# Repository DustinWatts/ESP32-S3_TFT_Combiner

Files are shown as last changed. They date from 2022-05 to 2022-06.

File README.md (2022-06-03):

# ESP32-S3-DevKitC-1 + Touchscreen Combiner PCB







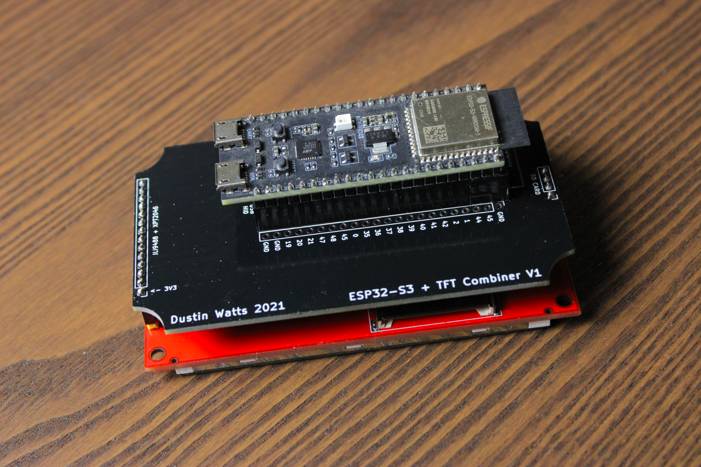
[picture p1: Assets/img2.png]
ESP32-S3-DevKitC-1 + Touchscreen Combiner PCB


A PCB making it easy to combine an ESP32-S3-DevKitC-1 and an ILI9488 TFT + XPT2046 Touchsceen. ***One big adavantage of the ESP32-S3 is that is has USB HID support. So you can use the extra USB port on the DevKitC to connect to your computer, so you can use a USB Keyboard instead of BLE!*** FreeTouchDeck already support this.

## Order directly from PCBWay

You can order the PCB's directly from PCBWay here: [Order PCBs from PCBWay](https://www.pcbway.com/project/shareproject/ESP32_S3_TFT_Combiner_V1_92bd8d61.html "Order the combiner board directly from PCBWay")

## Download Gebers and use your own fab house

If you want to use your own fab house, you can find the gerbers (as wel as a .zip file for easy upload) in the [Gerber folder](/Gerbers "Download the gerbers") in this repo.

## The PCB

The PCB is designed in KiCad and uses 22-pin double row headers for the ESP32-S3 so you can use the GPIO's not used by the screen. It also uses a 14-pin header for the screen and a 4-pin header for the SD card. I recommend using female headers so you can remove both the ESP32-S3 and the screen.

Pins used by the screen, touchcontroller and SD card are:

| ESP32-S3 | Function |
|---|---|
| GPIO4  | SD_SELECT  |
| GPIO5  | TFT_RESET  |
| GPIO6  | TFT_DC_RS  |
| GPIO7  | TFT_BACKLIGHT  |
| GPIO10  | TFT_SELECT  |
| GPIO11  | MOSI  |
| GPIO12  | SCK  |
| GPIO13  | MISO  |
| GPIO15  | TOUCH_SELECT  |
| GPIO16  | TOUCH_IRQ  |

And off course 3V3 and GND are connected to the screen. 

The rest of the pins you can freely use. Use the ESP32-S3-DevKitC-1 pinout card as a reference: [Pinout Card on espressif.com](https://docs.espressif.com/projects/esp-idf/en/latest/esp32s3/hw-reference/esp32s3/user-guide-devkitc-1.html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 "ESP32-S3-DevKitC-1 Pinout Card")

## The ESP32-S3
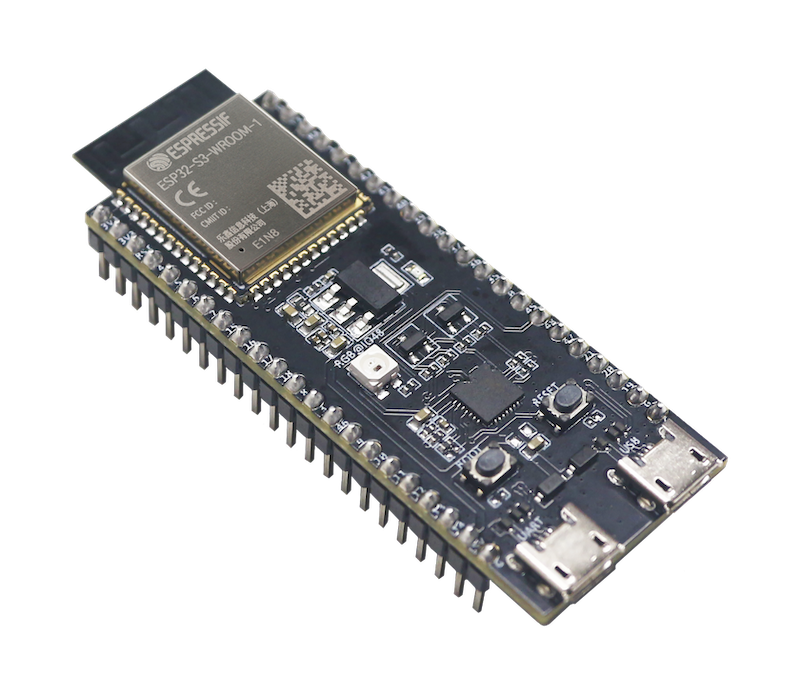
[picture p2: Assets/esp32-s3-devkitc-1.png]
ESP32-S3-DevKitC-1


The ESP32-S3 for this board is the ESP32-S3-DevKitC-1. Which is currently sold by:
- [Mouser](https://www.mouser.com/c/?q=ESP32-S3-DevKitC-1 "ESP32-S3-DevKitC-1 on Mouser")
- [DigiKey](https://www.digikey.nl/en/products/filter/rf-evaluation-and-development-kits-boards/859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 "ESP32-S3-DevKitC-1 on DigiKey")
- [Adafruit](https://www.adafruit.com/?q=ESP32-S3-DevKitC-1&sort=BestMatch "ESP32-S3-DevKitC-1 on Adafruit")
- [MakerFabs](https://www.makerfabs.com/search.html?&search=ESP32-S3-DevKitC-1 "ESP32-S3-DevKitC-1 on MakerFabs")

## The Touchsceen

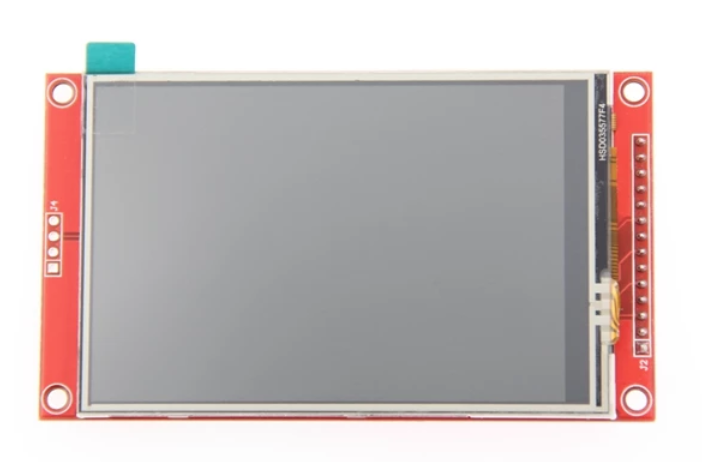
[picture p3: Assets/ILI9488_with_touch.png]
ILI9488 with Touch


The touchscreen used with this board is a 3.5" ILI9488 TFT with XPT2046 touchcontroller. You can find the screen here: 

- [AliExpress](https://s.click.aliexpress.com/e/_AMAa6B "Buy the ILI9488 with Touch on AliExpress") *
- [Amazon](https://amzn.to/3z2bf3f "Buy the ILI9488 with Touch on AliExpress") *

_* Afilliate link_

***Note: When you but the ILI9488 make sure you select the option "With Touch" if you have the possibility to do so!***

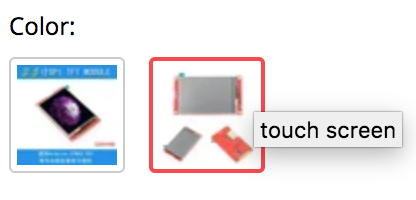
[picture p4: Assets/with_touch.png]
ILI9488 select with Touch


## The User_Setup.h

The User_Setup.h file in the folder with the same name is the User_Setup.h file you need to use the combiner PCB with the [TFT_eSPI](https://github.com/Bodmer/TFT_eSPI "TFT_eSPI lbrary by Bodmer") lbrary by Bodmer. Overwrite the contents of the original file and TFT_eSPI is now configured for use with the combiner board.

## FreeTouchDeck

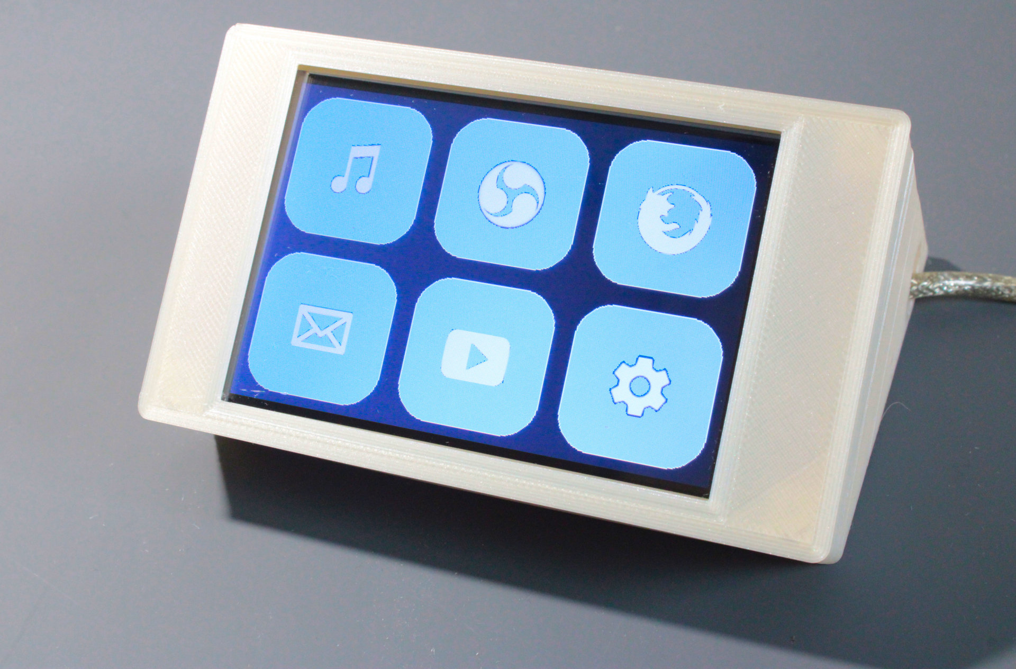
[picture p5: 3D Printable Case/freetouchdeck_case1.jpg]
FreeTouchDeck


FreeTouchDeck is currently being updated so it also supports the ESP32-S3. This also includes support for using the ESP32-S3 USB Keyboard HID. You can find the latest version here: https://github.com/DustinWatts/FreeTouchDeck. The updates are not in any release yet, you so you will have to download the source and compile it yourself. Hopefully this the next release will include ESP32-S3 support.

## The Case
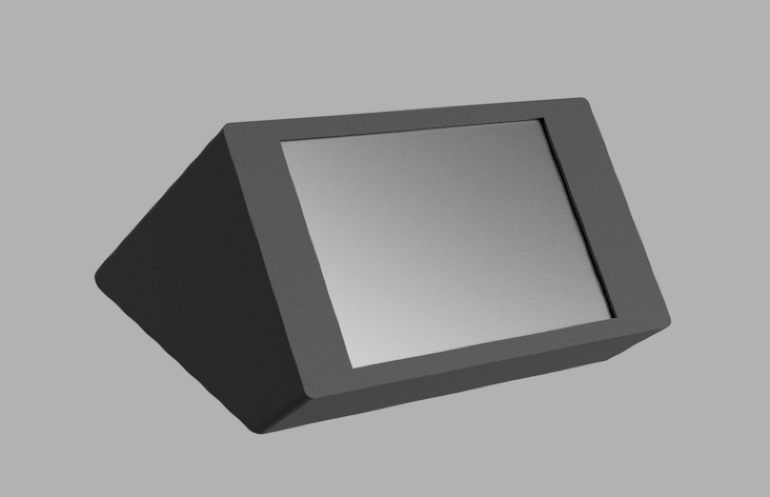
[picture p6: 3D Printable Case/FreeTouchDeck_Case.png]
3D Printable Case


The case was originally designed for the ESP32 + TFT combiner PCB and for use with FreeTouchDeck. But since the deminsions are the same, the case is also the same. You can find the .stl files to prin your own case in this repo in the folder called "3D Printable Case".

## Support Me

If you like what I am doing, there are a number of ways you can support me. 

| Platform | Link|
|:-----:|:-----|
| [Twtter](https://twitter.com/dustinwattsnl "Follow me on Twitter") | You can follow me on Twitter: [@dustinwattsnl](https://twitter.com/dustinwattsnl "Follow me on Twitter")|
| [YouTube](https://www.youtube.com/dustinwatts "Subscrive to my YouTube channel") | You can subscribe to my channel on Youtube: [/dustinWatts](https://www.youtube.com/dustinwatts "Subscribe to my YouTube channel") |
| [Patreon](https://www.patreon.com/dustinwatts) | You can support me by becoming a patron on Patreon: https://www.patreon.com/dustinwatts |
| [PayPal.me](https://www.paypal.me/dustinwattsnl) | You can make a one time donation using PayPal.me: https://www.paypal.me/dustinwattsnl |

## Get help

For quick acces to help you can join my Discord server: https://discord.gg/RE3XevS

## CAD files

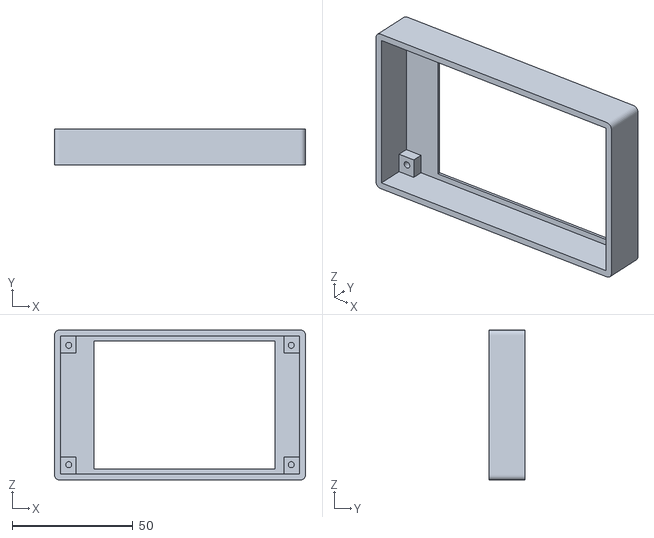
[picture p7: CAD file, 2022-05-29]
3D Printable Case/Top.stl
104.1 x 15.1 x 62.1

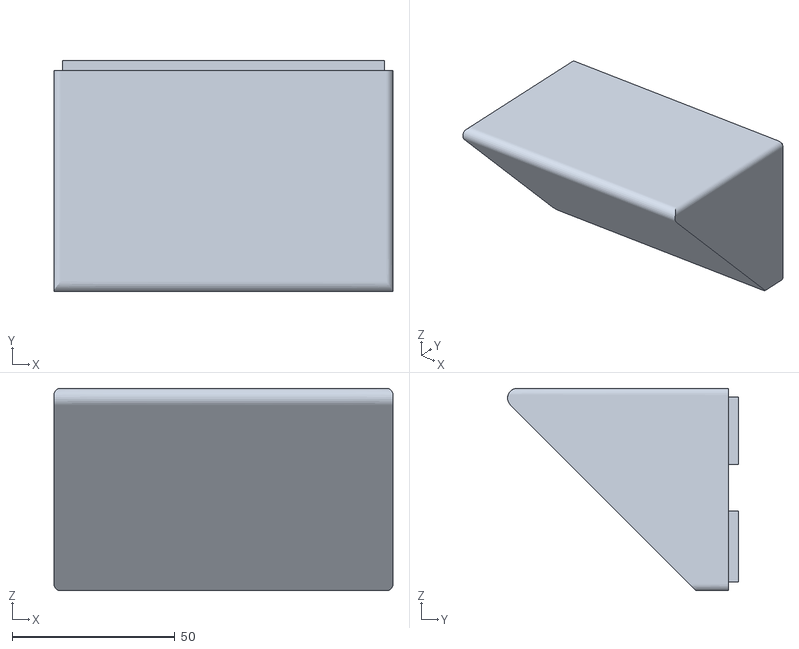
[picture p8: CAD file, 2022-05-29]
3D Printable Case/Bottom.stl
104.1 x 70.9 x 62.1

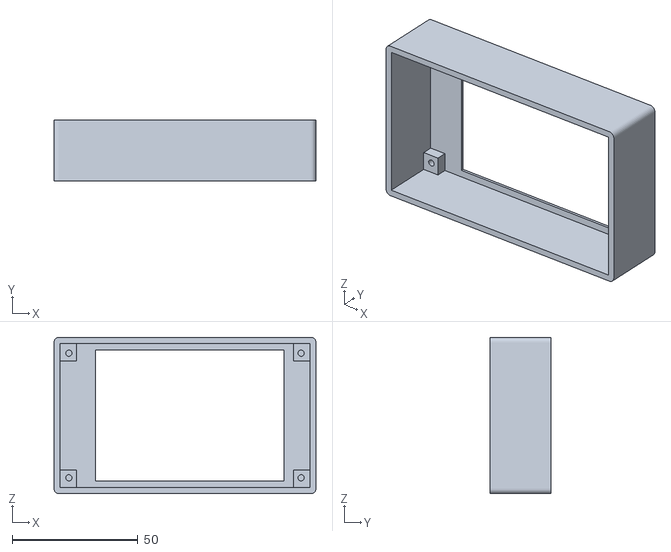
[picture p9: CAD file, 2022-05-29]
3D Printable Case/Top_for_TFT_with_Headers.stl
104.1 x 24.1 x 62.1

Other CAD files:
3D Printable Case/FreeTouchDeck Case V1.f3z

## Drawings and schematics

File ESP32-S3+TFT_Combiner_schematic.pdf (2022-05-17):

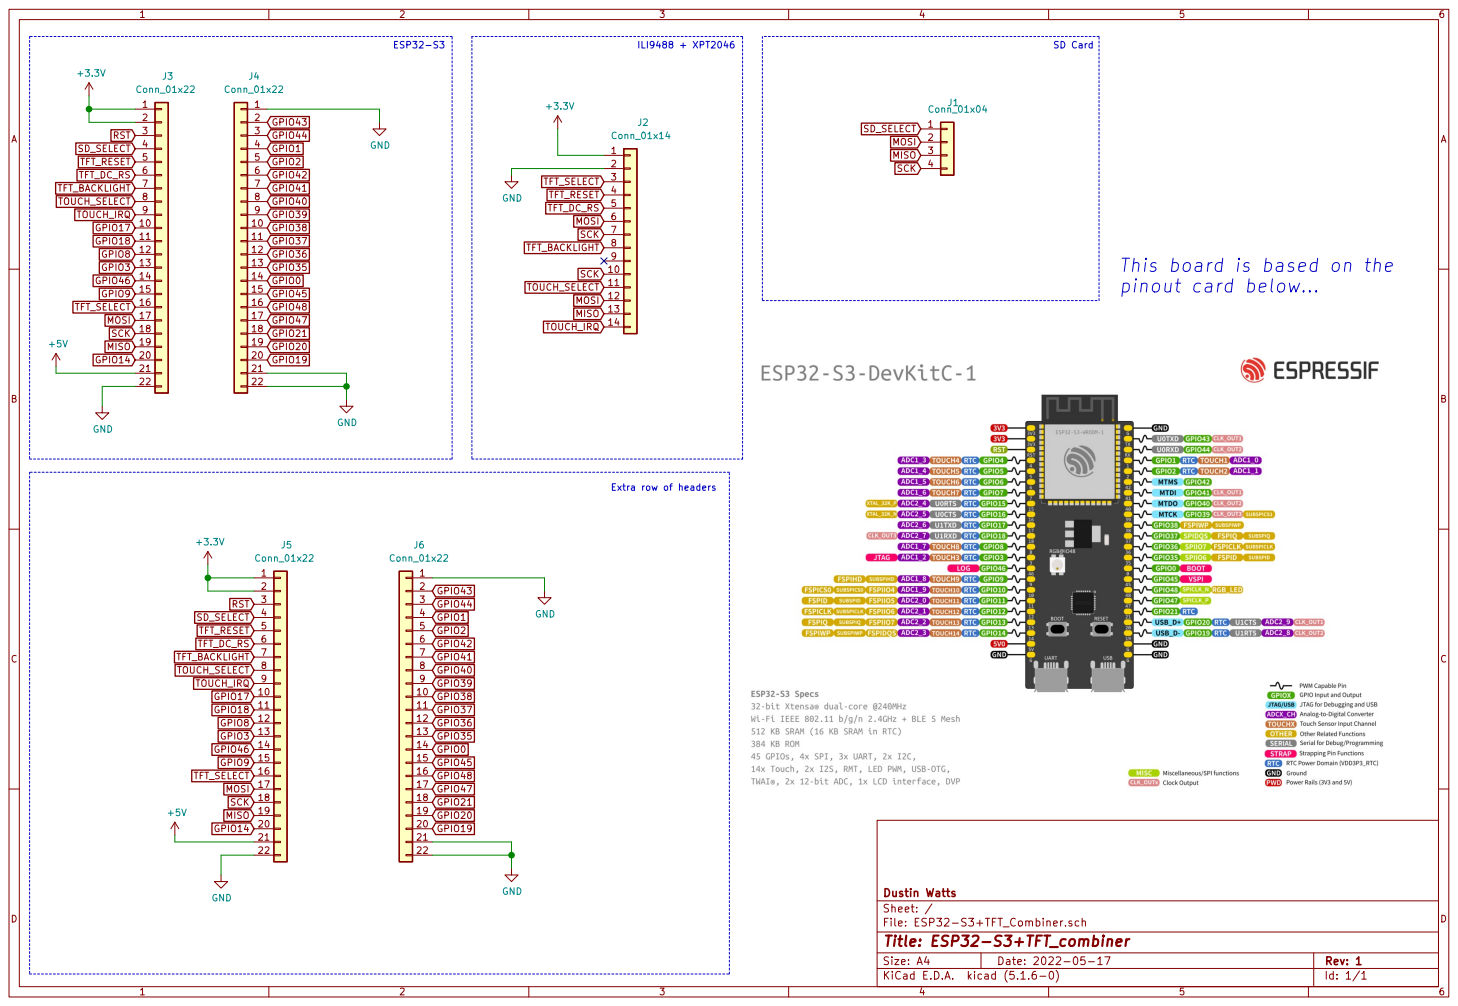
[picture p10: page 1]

File: ESP32-S3+TFT_Combiner.sch Sheet: / Dustin Watts

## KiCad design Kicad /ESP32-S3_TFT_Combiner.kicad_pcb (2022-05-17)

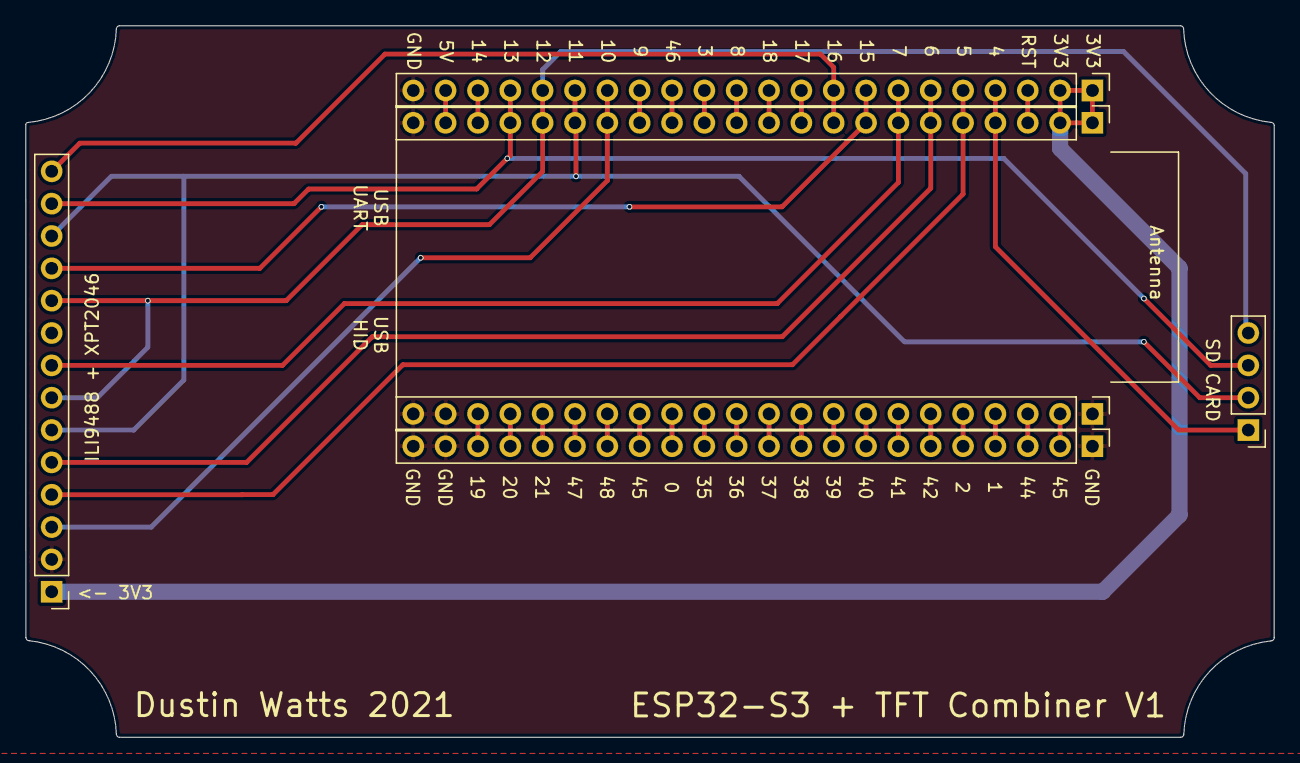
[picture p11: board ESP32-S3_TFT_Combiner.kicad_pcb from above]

Board: 2 copper layers, 98.0 x 55.9 mm, 6 parts (0 on the bottom side), 40 nets.

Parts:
J1: Conn_01x04; PinHeader_1x04_P2.54mm_Vertical
J2: Conn_01x14; PinHeader_1x14_P2.54mm_Vertical
J3, J4, J5, J6: Conn_01x22; PinHeader_1x22_P2.54mm_Vertical

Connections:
+3V3: J2.1, J3.1, J3.2, J5.1, J5.2
+5V: J3.21, J5.21
GND: J2.2, J3.22, J4.1, J4.21, J4.22, J5.22, J6.1, J6.21, J6.22
GPIO0: J4.14, J6.14
GPIO1: J4.4, J6.4
GPIO2: J4.5, J6.5
GPIO3: J3.13, J5.13
GPIO8: J3.12, J5.12
GPIO9: J3.15, J5.15
GPIO14: J3.20, J5.20
GPIO17: J3.10, J5.10
GPIO18: J3.11, J5.11
GPIO19: J4.20, J6.20
GPIO20: J4.19, J6.19
GPIO21: J4.18, J6.18
GPIO35: J4.13, J6.13
GPIO36: J4.12, J6.12
GPIO37: J4.11, J6.11
GPIO38: J4.10, J6.10
GPIO39: J4.9, J6.9
GPIO40: J4.8, J6.8
GPIO41: J4.7, J6.7
GPIO42: J4.6, J6.6
GPIO43: J4.2, J6.2
GPIO44: J4.3, J6.3
GPIO45: J4.15, J6.15
GPIO46: J3.14, J5.14
GPIO47: J4.17, J6.17
GPIO48: J4.16, J6.16
MISO: J1.3, J2.13, J3.19, J5.19
MOSI: J1.2, J2.6, J2.12, J3.17, J5.17
RST: J3.3, J5.3
SCK: J1.4, J2.7, J2.10, J3.18, J5.18
SD_SELECT: J1.1, J3.4, J5.4
TFT_BACKLIGHT: J2.8, J3.7, J5.7
TFT_DC_RS: J2.5, J3.6, J5.6
TFT_RESET: J2.4, J3.5, J5.5
TFT_SELECT: J2.3, J3.16, J5.16
TOUCH_IRQ: J2.14, J3.9, J5.9
TOUCH_SELECT: J2.11, J3.8, J5.8

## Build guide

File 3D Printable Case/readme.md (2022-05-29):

# FreeTouchDeck Case

**Pay attention! This case is for the combiner board. For the ESP32 TouchDown board, check this link: https://github.com/DustinWatts/esp32-touchdown/tree/main/Case**



You can print the case that will house both The ILI9488 + TFT screen and you ESP32 in a nice case. This housing is made with the ESP32 TFT Combiner PCB in mind, but will also work if you made your FreeTouchDeck on a prototyping board.

This case is made to have a press fit. If you are happy with your print and don't plan on taking it apart again, you could use some CA glue to hold the two halves together, but is it not necessary.

## Two different "Top" versions

There are two "Top" versions. The only difference is that one of them is a bit higher. If you use the TFT + ESP32 combiner PCB with female headers for the TFT it needs a slightly higher front. So if you are using female headers for the TFT --> use Top_for_TFT_with_Headers.stl!

# Print settings

I recommend the following settings when printing the case:

## Top

- Orientation: Flat side down
- Layer height: 0.2 mm
- Infill: 100%
- Support: none

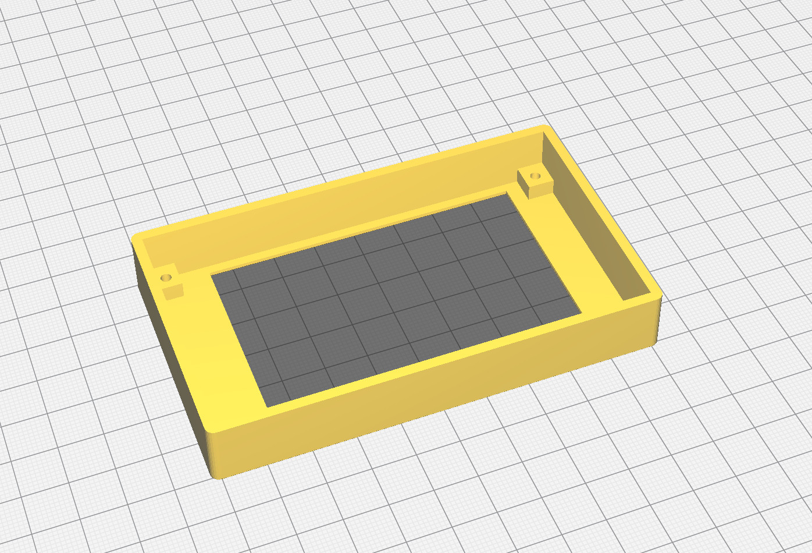
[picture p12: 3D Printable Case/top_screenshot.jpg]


## Top for TFT with Headers

- Orientation: Flat side down
- Layer height: 0.2 mm
- Infill: 100%
- Support: none

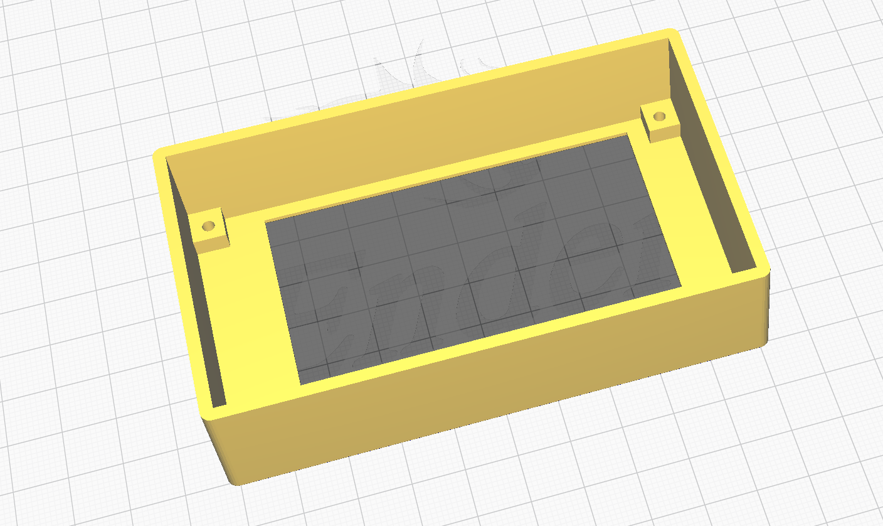
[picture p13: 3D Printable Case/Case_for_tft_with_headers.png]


## Bottom

- Orientation: The part that connects to the top down
- Layer Height: 0.2 mm
- Infill: 20%
- Support: Everywhere
- Support Overhang Angle: 70

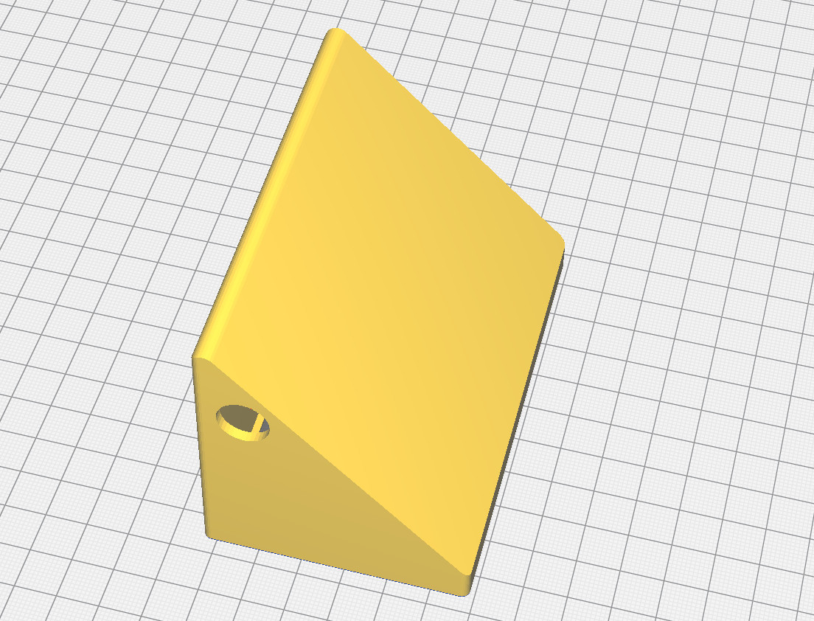
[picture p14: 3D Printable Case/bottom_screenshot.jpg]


Setting the Support Overhang Angle to 70 ensures that the hole for the USB cable and the the press fit ridge are properly supported, but doesn't over-support everything.

You can also download the case from Thingiverse: [FreeTouchDeck Case](https://www.thingiverse.com/thing:4661069)

Or any of the awesome cases other people have designed! [FreeTouchDeck Cases on Thingiverse](https://www.thingiverse.com/search?q=freetouchdeck&type=things&sort=relevant)

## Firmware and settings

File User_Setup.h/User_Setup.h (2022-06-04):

/* This is a stripped down version of a User_Setup.h file for TFT_eSPI

Copy the contents of this file to TFT_eSPI-master/User_setup.h 

This version is for the ESP32-S3-DevKitC-1 and an ILI9488 screen with resistive touch controller.

*/

#define ILI9488_DRIVER     // WARNING: Do not connect ILI9488 display SDO to MISO if other devices share the SPI bus (TFT SDO does NOT tristate when CS is high)

#define TFT_BL    7            // LED back-light control pin

#define TFT_MISO  13
#define TFT_MOSI  11
#define TFT_SCLK  12
#define TFT_CS    10  // Chip select control pin
#define TFT_DC    6  // Data Command control pin
#define TFT_RST   5  // Reset pin (could connect to RST pin)

#define TOUCH_CS  15     // Chip select pin (T_CS) of touch screen

#define LOAD_GLCD   // Font 1. Original Adafruit 8 pixel font needs ~1820 bytes in FLASH
#define LOAD_FONT2  // Font 2. Small 16 pixel high font, needs ~3534 bytes in FLASH, 96 characters
#define LOAD_FONT4  // Font 4. Medium 26 pixel high font, needs ~5848 bytes in FLASH, 96 characters
#define LOAD_FONT6  // Font 6. Large 48 pixel font, needs ~2666 bytes in FLASH, only characters 1234567890:-.apm
#define LOAD_FONT7  // Font 7. 7 segment 48 pixel font, needs ~2438 bytes in FLASH, only characters 1234567890:-.
#define LOAD_FONT8  // Font 8. Large 75 pixel font needs ~3256 bytes in FLASH, only characters 1234567890:-.

#define LOAD_GFXFF  // FreeFonts. Include access to the 48 Adafruit_GFX free fonts FF1 to FF48 and custom fonts

#define SMOOTH_FONT

#define SPI_FREQUENCY  27000000
#define SPI_READ_FREQUENCY  20000000
#define SPI_TOUCH_FREQUENCY  2500000

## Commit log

2022-05-17 Added Kicad Project
    Kicad project, including .kicad_pcb, .net, .pro, and .sch
    [ESP32-S3+TFT_Combiner.kicad_pcb, ESP32-S3+TFT_Combiner.sch]
2022-05-17 Added schematic in PDF format
    Rev 1 schematic added.
2022-05-17 Updated Silkscreen
    Added pin numbering and correct a spelling mistake (XTP2040 = XPT2046)
    [ESP32-S3+TFT_Combiner.kicad_pcb]
2022-05-17 Added Gerbers
    Added gerber files and also a .zip file containing all the gerbers for easy upload.
    [ESP32-S3+TFT_Combiner-B_Cu.gbl, ESP32-S3+TFT_Combiner-B_Mask.gbs, ESP32-S3+TFT_Combiner-B_Paste.gbp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]
2022-05-29 Update User_Setup.h
    Typo corrections.
    [User_Setup.h]
2022-05-29 Clean up schematic
    Nothing has changed, just making it look nicer.
    [ESP32-S3+TFT_Combiner.sch]
2022-05-29 Add 3D Printable Case
    [Bottom.stl, FreeTouchDeck Case V1.f3z, Top.stl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]
2022-06-05 Rename files
    Replaced + by _
    [ESP32-S3_TFT_Combiner.kicad_pcb, ESP32-S3_TFT_Combiner.sch]
